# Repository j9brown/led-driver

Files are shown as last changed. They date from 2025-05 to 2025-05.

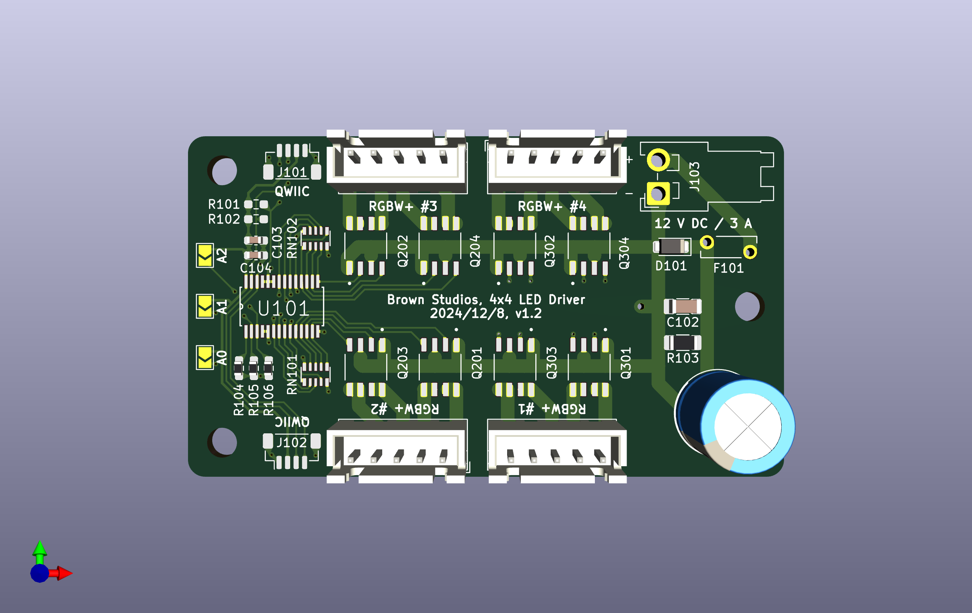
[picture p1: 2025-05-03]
hardware/led-driver-pcb.png

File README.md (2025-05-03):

# LED Driver

Drives 4 RGB/W LEDs with PWM for a total of up to 3 A controlled over an I2C bus.

## Design

This design is based around a [PCA9685](https://www.nxp.com/docs/en/data-sheet/PCA9685.pdf) I2C PWM chip with 16 channels.  Each channel drives an N-channel MOSFET low-side switch.  Each group of 4 channels and a positive common rail feeds a JST XH 5-pin connector to which an RGB/W LED lamp may be attached.

The I2C bus must be referenced to the same ground as the negative input.

The board is designed for use with a 12 V nominal power supply but should work with anything from about 5 V to 16 V.  It includes a 3 A polyfuse and transient voltage suppression.  In case of reverse polarity connection, the TVS shunts the power input across the polyfuse.

## Notice

The software, documentation, design, and all copyright protected artifacts are released under the terms of the [MIT license](LICENSE).

The hardware is released under the terms of the [CERN-OHL-W license](hardware/LICENSE).

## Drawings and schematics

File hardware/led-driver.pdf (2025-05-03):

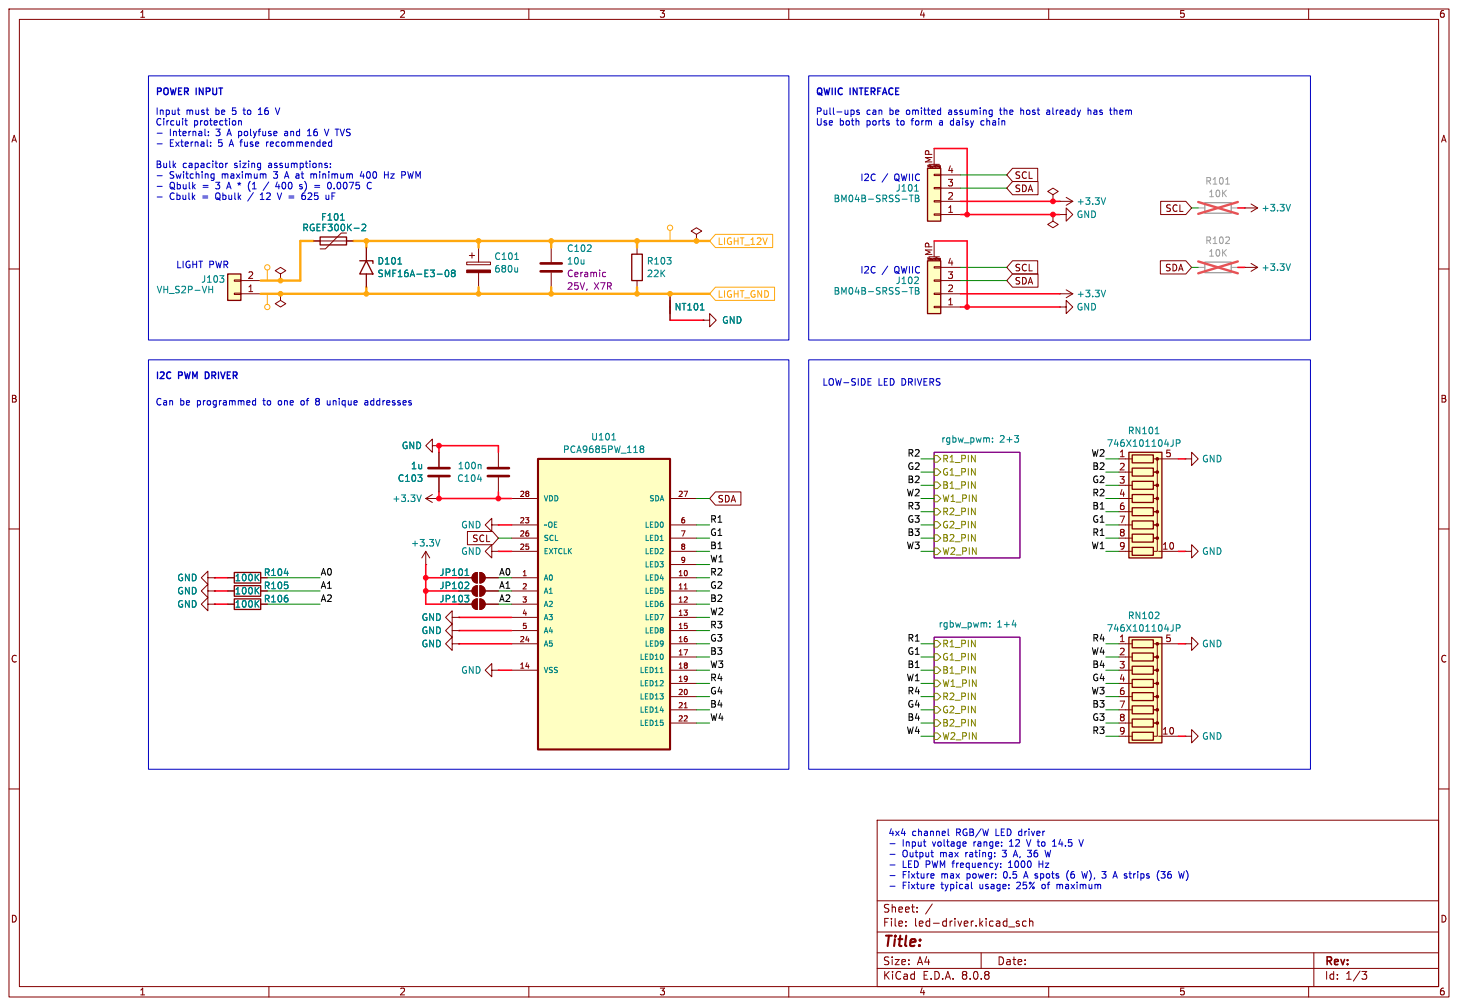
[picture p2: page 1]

POWER INPUT
Input must be 5 to 16 V Circuit protection

I2C / QWIIC QWIIC INTERFACE
Use both ports to form a daisy chain

LOW-SIDE LED DRIVERS D101 SMF16A-E3-08 GND GND GND GND
LIGHT PWR
+3.3V GND GND

4x4 channel RGB/W LED driver
- Input voltage range: 12 V to 14.5 V
- Output max rating: 3 A, 36 W
- Fixture max power: 0.5 A spots (6 W), 3 A strips (36 W)

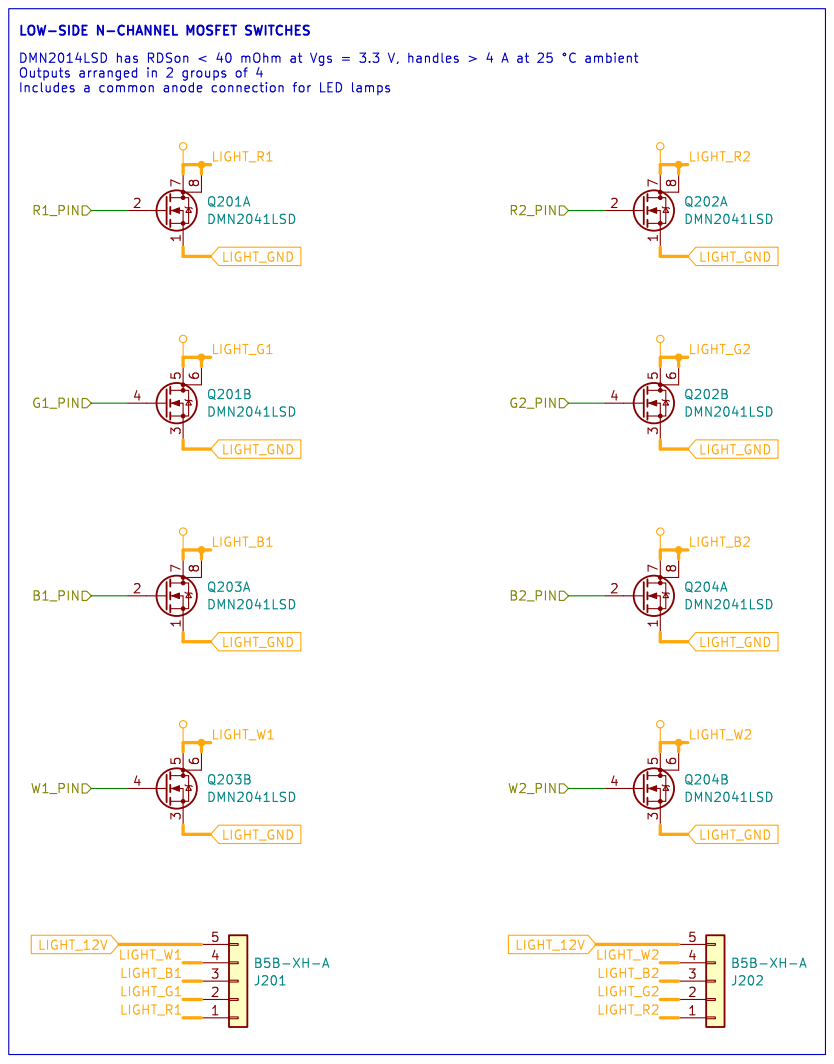
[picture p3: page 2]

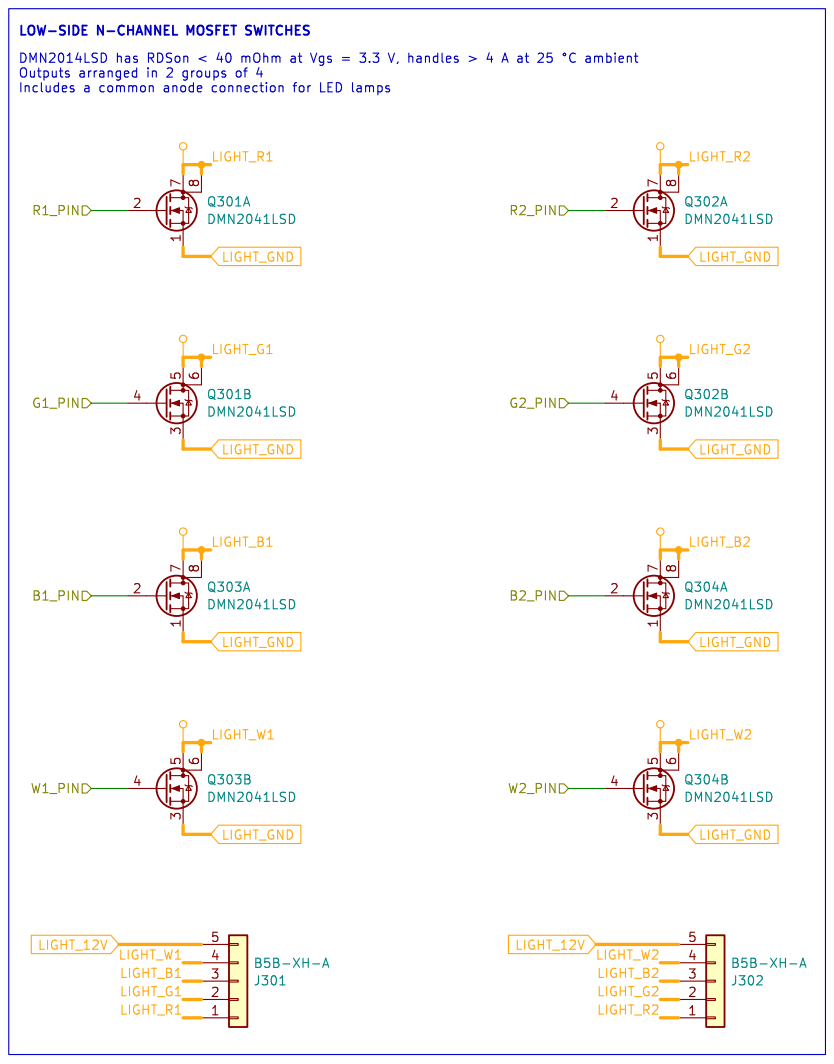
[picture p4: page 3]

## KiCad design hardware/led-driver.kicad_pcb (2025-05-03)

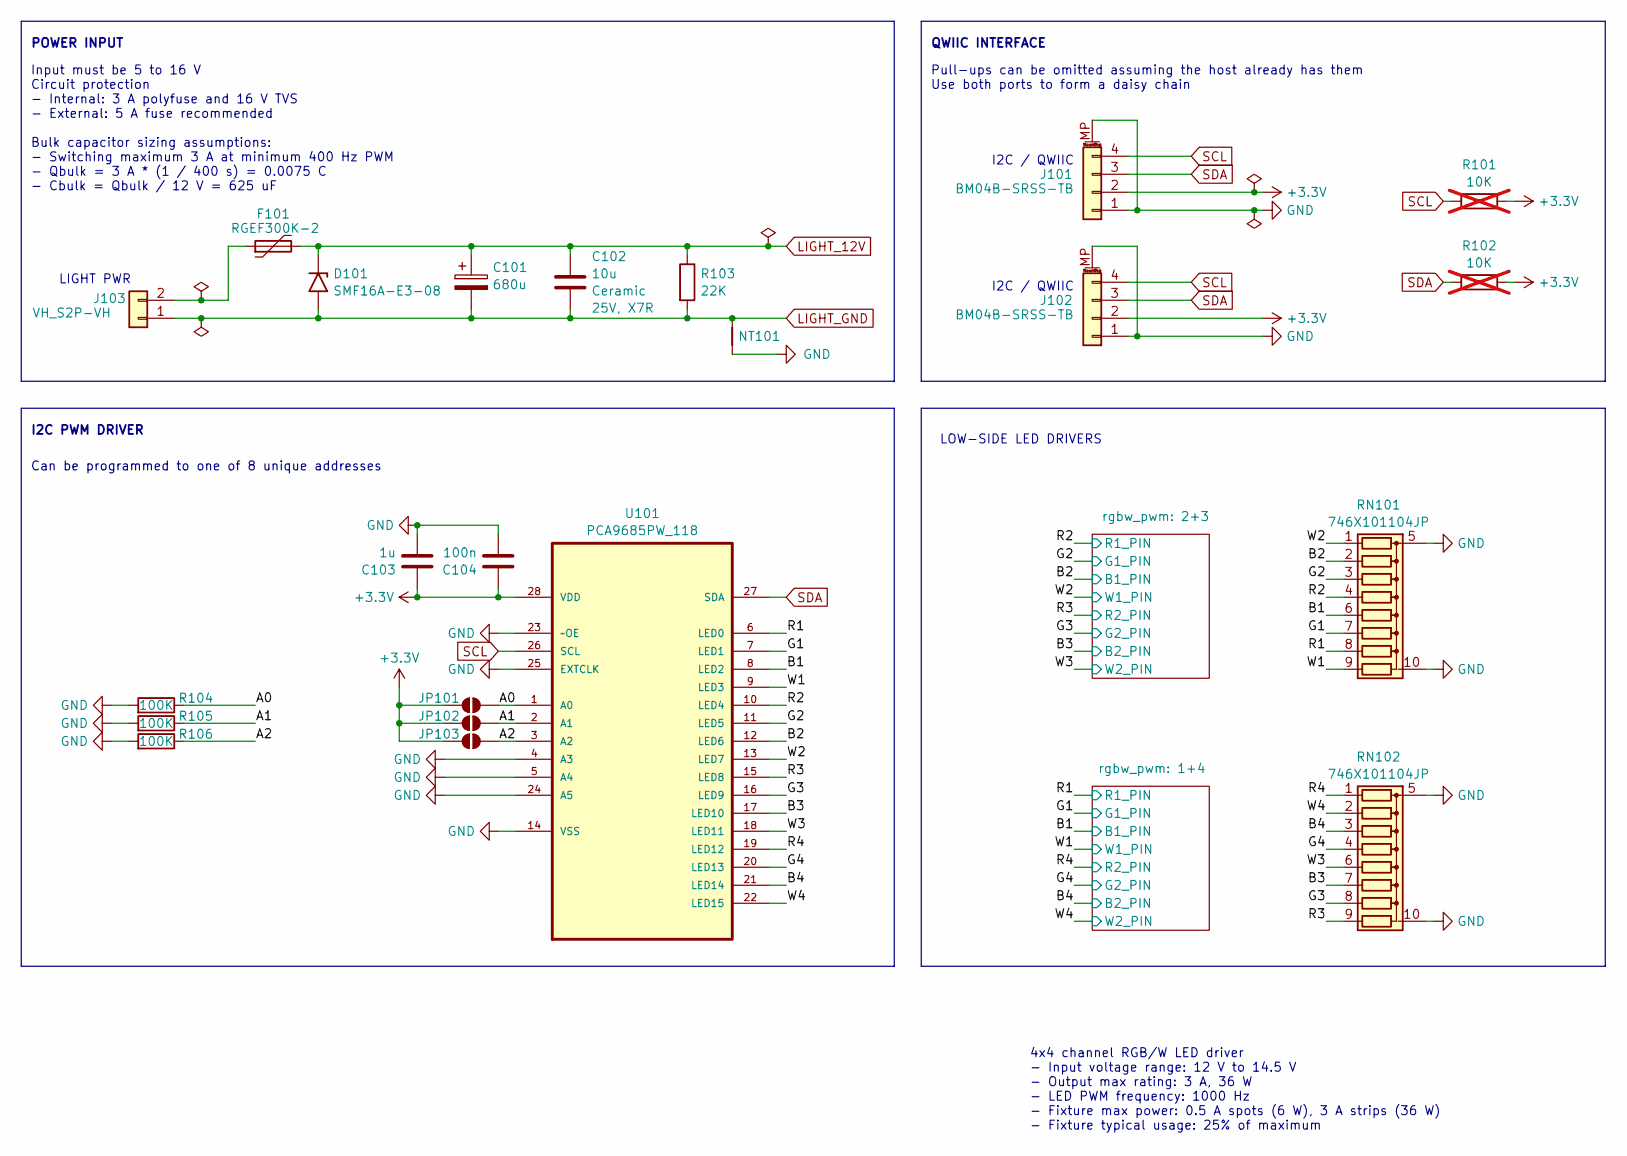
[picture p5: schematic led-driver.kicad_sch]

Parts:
C101: 680u; CP_Radial_D10.0mm_P5.00mm; Part EKZH160ELL681MJC5S
C102: 10u; C_1206_3216Metric_Pad1.33x1.80mm_HandSolder; Rating 25V, X7R
C103: 1u; C_0603_1608Metric_Pad1.08x0.95mm_HandSolder
C104: 100n; C_0603_1608Metric_Pad1.08x0.95mm_HandSolder
D101: SMF16A-E3-08; D_SMF
F101: RGEF300K-2; FUSRR505W81L660T250H1360
J101, J102: BM04B-SRSS-TB; JST_SH_BM04B-SRSS-TB_1x04-1MP_P1.00mm_Vertical
J103: VH_S2P-VH; JST_VH_S2P-VH_1x02_P3.96mm_Horizontal
JP101, JP102, JP103: SolderJumper_2_Open; SolderJumper-2_P1.3mm_Open_TrianglePad1.0x1.5mm
NT101: NetTie_2; NetTie-2_SMD_Pad1.6mm
R101, R102: 10K; R_0603_1608Metric_Pad0.98x0.95mm_HandSolder; not fitted
R103: 22K; R_1206_3216Metric_Pad1.30x1.75mm_HandSolder
R104, R105, R106: 100K; R_0603_1608Metric_Pad0.98x0.95mm_HandSolder
RN101, RN102: 746X101104JP; RESCAXS64P320X160X70-10N
U101: PCA9685PW_118; SOP65P640X110-28N; MPN PCA9685PW,118

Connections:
+3.3V: C103.1, C104.1, J101.2, J102.2, JP101.1 (A), JP102.1 (A), JP103.1 (A), R101.1, R102.1, U101.28 (VDD)
/A0: JP101.2 (B), R104.1, U101.1 (A0)
/A1: JP102.2 (B), R105.1, U101.2 (A1)
/A2: JP103.2 (B), R106.1, U101.3 (A2)
/B1: RN101.6 (R5), U101.8 (LED2); also elsewhere on the board
/B2: RN101.2 (R2), U101.12 (LED6); also elsewhere on the board
/B3: RN102.7 (R6), U101.17 (LED10); also elsewhere on the board
/B4: RN102.3 (R3), U101.21 (LED14); also elsewhere on the board
/G1: RN101.7 (R6), U101.7 (LED1); also elsewhere on the board
/G2: RN101.3 (R3), U101.11 (LED5); also elsewhere on the board
/G3: RN102.8 (R7), U101.16 (LED9); also elsewhere on the board
/G4: RN102.4 (R4), U101.20 (LED13); also elsewhere on the board
/R1: RN101.8 (R7), U101.6 (LED0); also elsewhere on the board
/R2: RN101.4 (R4), U101.10 (LED4); also elsewhere on the board
/R3: RN102.9 (R8), U101.15 (LED8); also elsewhere on the board
/R4: RN102.1 (R1), U101.19 (LED12); also elsewhere on the board
/W1: RN101.9 (R8), U101.9 (LED3); also elsewhere on the board
/W2: RN101.1 (R1), U101.13 (LED7); also elsewhere on the board
/W3: RN102.6 (R5), U101.18 (LED11); also elsewhere on the board
/W4: RN102.2 (R2), U101.22 (LED15); also elsewhere on the board
GND: C103.2, C104.2, J101.1, J101.MP (MountPin), J102.1, J102.MP (MountPin), NT101.1, R104.2, R105.2, R106.2, RN101.5 (common), RN101.10 (common), RN102.5 (common), RN102.10 (common), U101.4 (A3), U101.5 (A4), U101.14 (VSS), U101.23 (~OE), U101.24 (A5), U101.25 (EXTCLK)
LIGHT_12V: C101.1, C102.1, D101.1 (A1), F101.2, R103.1; also elsewhere on the board
LIGHT_GND: C101.2, C102.2, D101.2 (A2), J103.1, NT101.2, R103.2; also elsewhere on the board
unnamed: F101.1, J103.2
SCL: J101.4, J102.4, R101.2, U101.26 (SCL)
SDA: J101.3, J102.3, R102.2, U101.27 (SDA)

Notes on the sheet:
4x4 channel RGB/W LED driver - Input voltage range: 12 V to 14.5 V - Output max rating: 3 A, 36 W - LED PWM frequency: 1000 Hz - Fixture max power: 0.5 A spots (6 W), 3 A strips (36 W) - Fixture typical usage: 25% of maximum
QWIIC INTERFACE
I2C PWM DRIVER
POWER INPUT
LOW-SIDE LED DRIVERS
I2C / QWIIC
Pull-ups can be omitted assuming the host already has them Use both ports to form a daisy chain
Input must be 5 to 16 V Circuit protection - Internal: 3 A polyfuse and 16 V TVS - External: 5 A fuse recommended Bulk capacitor sizing assumptions: - Switching maximum 3 A at minimum 400 Hz PWM - Qbulk = 3 A * (1 / 400 s) = 0.0075 C - Cbulk = Qbulk / 12 V = 625 uF
LIGHT PWR
Can be programmed to one of 8 unique addresses

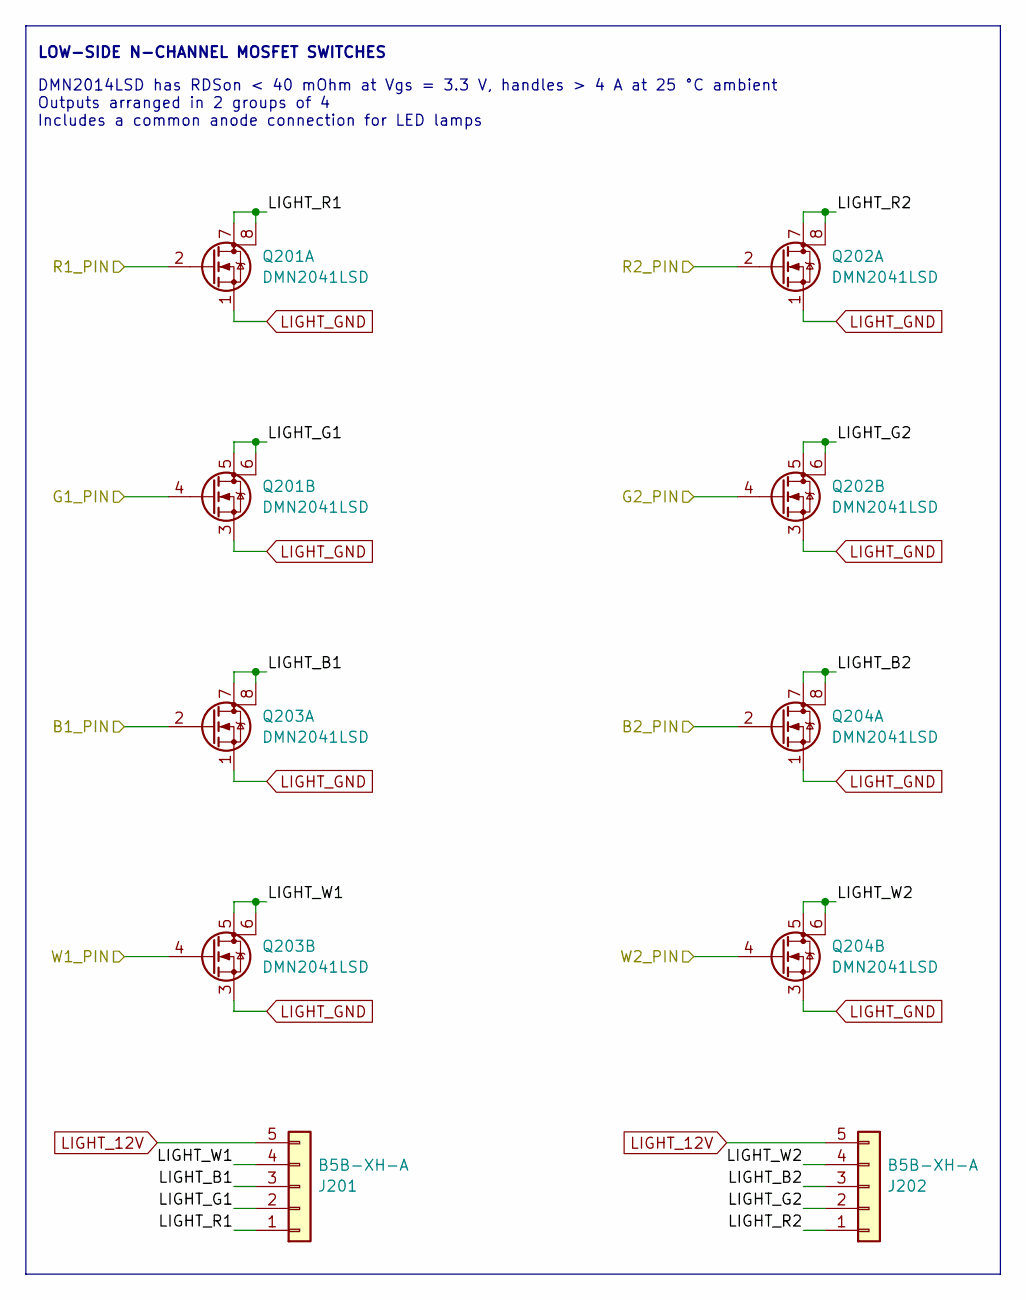
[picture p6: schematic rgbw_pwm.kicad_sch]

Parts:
J201, J202: B5B-XH-A; JST_XH_B5B-XH-A_1x05_P2.50mm_Vertical
Q201, Q202, Q203, Q204: DMN2041LSD; SOIC127P600X175-8N

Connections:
/B2: Q203.2 (G); also elsewhere on the board
/B3: Q204.2 (G); also elsewhere on the board
/G2: Q201.4 (G); also elsewhere on the board
/G3: Q202.4 (G); also elsewhere on the board
/R2: Q201.2 (G); also elsewhere on the board
/R3: Q202.2 (G); also elsewhere on the board
/W2: Q203.4 (G); also elsewhere on the board
/W3: Q204.4 (G); also elsewhere on the board
/rgbw_pwm: 2+3/LIGHT_B1: J201.3, Q203.7 (D), Q203.8 (D)
/rgbw_pwm: 2+3/LIGHT_B2: J202.3, Q204.7 (D), Q204.8 (D)
/rgbw_pwm: 2+3/LIGHT_G1: J201.2, Q201.5 (D), Q201.6 (D)
/rgbw_pwm: 2+3/LIGHT_G2: J202.2, Q202.5 (D), Q202.6 (D)
/rgbw_pwm: 2+3/LIGHT_R1: J201.1, Q201.7 (D), Q201.8 (D)
/rgbw_pwm: 2+3/LIGHT_R2: J202.1, Q202.7 (D), Q202.8 (D)
/rgbw_pwm: 2+3/LIGHT_W1: J201.4, Q203.5 (D), Q203.6 (D)
/rgbw_pwm: 2+3/LIGHT_W2: J202.4, Q204.5 (D), Q204.6 (D)
LIGHT_12V: J201.5, J202.5; also elsewhere on the board
LIGHT_GND: Q201.1 (S), Q201.3 (S), Q202.1 (S), Q202.3 (S), Q203.1 (S), Q203.3 (S), Q204.1 (S), Q204.3 (S); also elsewhere on the board

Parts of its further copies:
J301, J302: B5B-XH-A; JST_XH_B5B-XH-A_1x05_P2.50mm_Vertical
Q301, Q302, Q303, Q304: DMN2041LSD; SOIC127P600X175-8N

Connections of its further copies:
/B1: Q303.2 (G); also elsewhere on the board
/B4: Q304.2 (G); also elsewhere on the board
/G1: Q301.4 (G); also elsewhere on the board
/G4: Q302.4 (G); also elsewhere on the board
/R1: Q301.2 (G); also elsewhere on the board
/R4: Q302.2 (G); also elsewhere on the board
/W1: Q303.4 (G); also elsewhere on the board
/W4: Q304.4 (G); also elsewhere on the board
/rgbw_pwm: 1+4/LIGHT_B1: J301.3, Q303.7 (D), Q303.8 (D)
/rgbw_pwm: 1+4/LIGHT_B2: J302.3, Q304.7 (D), Q304.8 (D)
/rgbw_pwm: 1+4/LIGHT_G1: J301.2, Q301.5 (D), Q301.6 (D)
/rgbw_pwm: 1+4/LIGHT_G2: J302.2, Q302.5 (D), Q302.6 (D)
/rgbw_pwm: 1+4/LIGHT_R1: J301.1, Q301.7 (D), Q301.8 (D)
/rgbw_pwm: 1+4/LIGHT_R2: J302.1, Q302.7 (D), Q302.8 (D)
/rgbw_pwm: 1+4/LIGHT_W1: J301.4, Q303.5 (D), Q303.6 (D)
/rgbw_pwm: 1+4/LIGHT_W2: J302.4, Q304.5 (D), Q304.6 (D)
LIGHT_12V: J301.5, J302.5; also elsewhere on the board
LIGHT_GND: Q301.1 (S), Q301.3 (S), Q302.1 (S), Q302.3 (S), Q303.1 (S), Q303.3 (S), Q304.1 (S), Q304.3 (S); also elsewhere on the board

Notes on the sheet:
DMN2014LSD has RDSon < 40 mOhm at Vgs = 3.3 V, handles > 4 A at 25 °C ambient Outputs arranged in 2 groups of 4 Includes a common anode connection for LED lamps
LOW-SIDE N-CHANNEL MOSFET SWITCHES

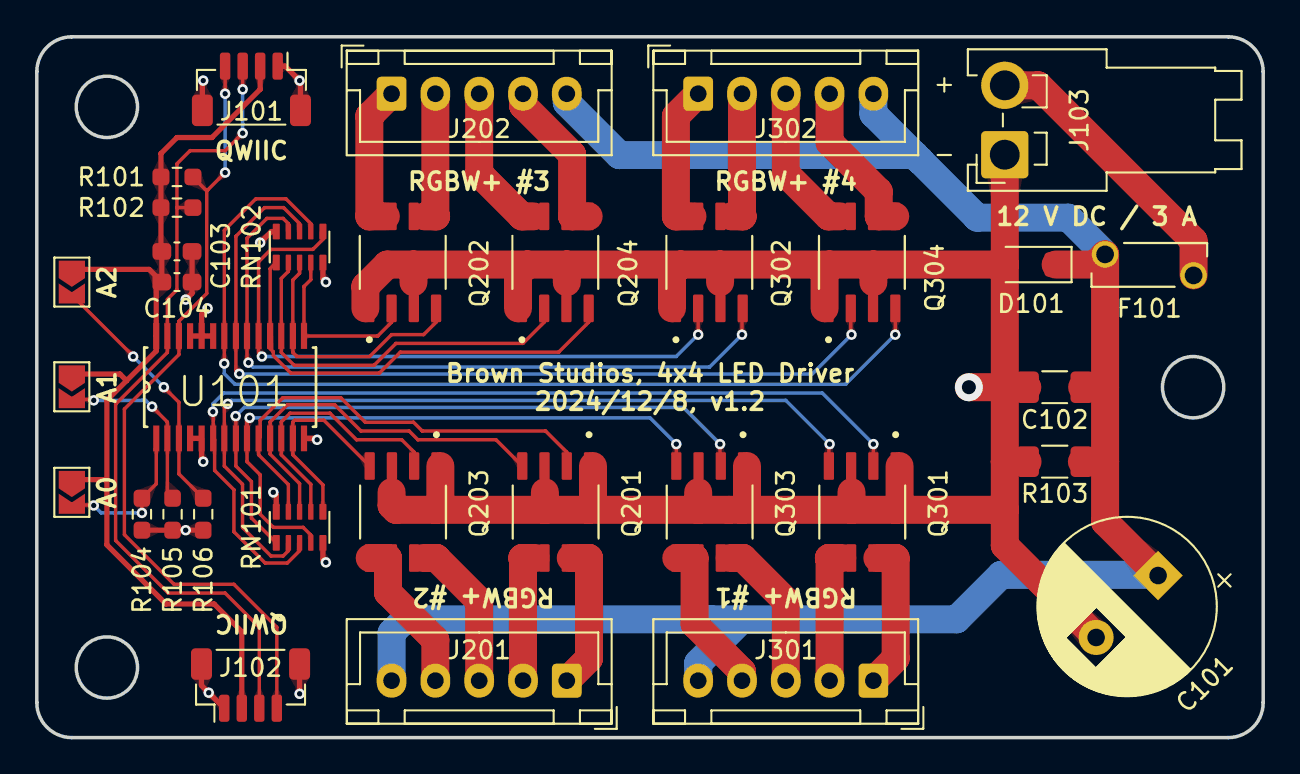
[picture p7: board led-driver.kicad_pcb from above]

Board: 2 copper layers, 70.0 x 40.0 mm, 34 parts (0 on the bottom side), 42 nets.

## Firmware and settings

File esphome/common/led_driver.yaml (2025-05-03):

# LED DRIVER PACKAGE
#
# ESPHome package for the LED driver board.
#
# Include the contents of this file into your device configuration YAML
# file as a package like this (recommended).  Update the I2C bus ID,
# I2C address, and other parameters for your usage.
#
# packages:
#   led_drivers:
#     substitutions:
#       # Adjust the white point to produce a warmer white with less blue
#       # Reduce overall power of RGB to avoid excess heat production
#       spot_red_max_power: 25%
#       spot_green_max_power: 25%
#       spot_blue_max_power: 6.5%
#       spot_white_max_power: 100%
#       strip_red_max_power: 25%
#       strip_green_max_power: 25%
#       strip_blue_max_power: 6.5%
#       strip_white_max_power: 100%
#   <<: !include
#     file: common/led_driver.yaml
#     vars:
#       i2c_id: i2c_main
#       address: 0x42
#       light_1_name: 'Hall Front'
#       light_1_type: spot
#       light_2_name: 'Hall Rear'
#       light_2_type: spot
#       light_3_name: 'Entry'
#       light_3_type: spot
#       light_4_name: 'Galley'
#       light_4_type: strip
#   <<: !include
#     file: common/led_driver.yaml
#     vars:
#       i2c_id: i2c_main
#       address: 0x44
#       light_1_name: 'Bedroom Front Right'
#       light_1_type: spot
#       light_2_name: 'Bedroom Rear Right'
#       light_2_type: spot
#       light_3_name: 'Bedroom Rear Left'
#       light_3_type: spot
#       light_4_name: 'Bedroom Front Left'
#       light_4_type: spot
led_driver_${address}:
  pca9685:
    - id: pca9685_${address}
      i2c_id: ${i2c_id}
      address: ${address}
      frequency: 400
  output:
    - platform: pca9685
      id: light_${address}_1_r
      pca9685_id: pca9685_${address}
      channel: 0
      max_power: ${${light_1_type}_red_max_power}
    - platform: pca9685
      id: light_${address}_1_g
      pca9685_id: pca9685_${address}
      channel: 1
      max_power: ${${light_1_type}_green_max_power}
    - platform: pca9685
      id: light_${address}_1_b
      pca9685_id: pca9685_${address}
      channel: 2
      max_power: ${${light_1_type}_blue_max_power}
    - platform: pca9685
      id: light_${address}_1_w
      pca9685_id: pca9685_${address}
      channel: 3
      max_power: ${${light_1_type}_white_max_power}
    - platform: pca9685
      id: light_${address}_2_r
      pca9685_id: pca9685_${address}
      channel: 4
      max_power: ${${light_2_type}_red_max_power}
    - platform: pca9685
      id: light_${address}_2_g
      pca9685_id: pca9685_${address}
      channel: 5
      max_power: ${${light_2_type}_green_max_power}
    - platform: pca9685
      id: light_${address}_2_b
      pca9685_id: pca9685_${address}
      channel: 6
      max_power: ${${light_2_type}_blue_max_power}
    - platform: pca9685
      id: light_${address}_2_w
      pca9685_id: pca9685_${address}
      channel: 7
      max_power: ${${light_2_type}_white_max_power}
    - platform: pca9685
      id: light_${address}_3_r
      pca9685_id: pca9685_${address}
      channel: 8
      max_power: ${${light_3_type}_red_max_power}
    - platform: pca9685
      id: light_${address}_3_g
      pca9685_id: pca9685_${address}
      channel: 9
      max_power: ${${light_3_type}_green_max_power}
    - platform: pca9685
      id: light_${address}_3_b
      pca9685_id: pca9685_${address}
      channel: 10
      max_power: ${${light_3_type}_blue_max_power}
    - platform: pca9685
      id: light_${address}_3_w
      pca9685_id: pca9685_${address}
      channel: 11
      max_power: ${${light_3_type}_white_max_power}
    - platform: pca9685
      id: light_${address}_4_r
      pca9685_id: pca9685_${address}
      channel: 12
      max_power: ${${light_4_type}_red_max_power}
    - platform: pca9685
      id: light_${address}_4_g
      pca9685_id: pca9685_${address}
      channel: 13
      max_power: ${${light_4_type}_green_max_power}
    - platform: pca9685
      id: light_${address}_4_b
      pca9685_id: pca9685_${address}
      channel: 14
      max_power: ${${light_4_type}_blue_max_power}
    - platform: pca9685
      id: light_${address}_4_w
      pca9685_id: pca9685_${address}
      channel: 15
      max_power: ${${light_4_type}_white_max_power}
  light:
    - platform: rgbw
      id: light_${address}_1
      name: ${light_1_name}
      red: light_${address}_1_r
      green: light_${address}_1_g
      blue: light_${address}_1_b
      white: light_${address}_1_w
      restore_mode: ALWAYS_OFF
      default_transition_length: 0.5s
    - platform: rgbw
      id: light_${address}_2
      name: ${light_2_name}
      red: light_${address}_2_r
      green: light_${address}_2_g
      blue: light_${address}_2_b
      white: light_${address}_2_w
      restore_mode: ALWAYS_OFF
      default_transition_length: 0.5s
    - platform: rgbw
      id: light_${address}_3
      name: ${light_3_name}
      red: light_${address}_3_r
      green: light_${address}_3_g
      blue: light_${address}_3_b
      white: light_${address}_3_w
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

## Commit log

2025-05-03 Initial import of the project.
    [led-driver.kicad_pcb, led-driver.kicad_sch, rgbw_pwm.kicad_sch]
2025-05-03 Tidy up the schematic.
    [led-driver.kicad_pcb, led-driver.kicad_sch, rgbw_pwm.kicad_sch]
2025-05-03 Add PCB rendering
